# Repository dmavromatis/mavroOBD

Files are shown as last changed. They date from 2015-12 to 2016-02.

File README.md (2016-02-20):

# mavroOBD
Arduino (328P) based OBD port module

The goal of this project it to create an Arduino based OBD port module that can be used to enhance a vehicles capabilites.  For example, if you want door locks to close when moving faster than 5mph or to invoke/emulate certain CANbus buttons automatically at start up.

I have uploaded board designs for an OBD module I puchased from China.  It's a two board design.  Lower board solders to the pins of the OBD module and provides a 12V > 5V power supply.  Headers connect to the top board where the Atmel 328P and Microchip MCP2515 CAN Bus controller with SPI interface and MCP2551 CAN transceiver.

This project is based on an Arduino Uno and SeedStudio CAN shield just miniturized to fit in a OBD module.

The module enclousure was purchased from a company in China called AOTAI Industry Co.<br>
Part #: AOT-130N - ODB Connector with housing<br/>
Website: www.aotsisz.com

--------
License
--------

If you are distributing a modified version of the project, please describe the dates and details of your modifications (as described in section 3.3b of the CERN open hardware license).  If you are using a publicly available repository to track changes (which we encourage), you may simply list the URL of the repository here.

https://github.com/dmavromatis/mavroOBD

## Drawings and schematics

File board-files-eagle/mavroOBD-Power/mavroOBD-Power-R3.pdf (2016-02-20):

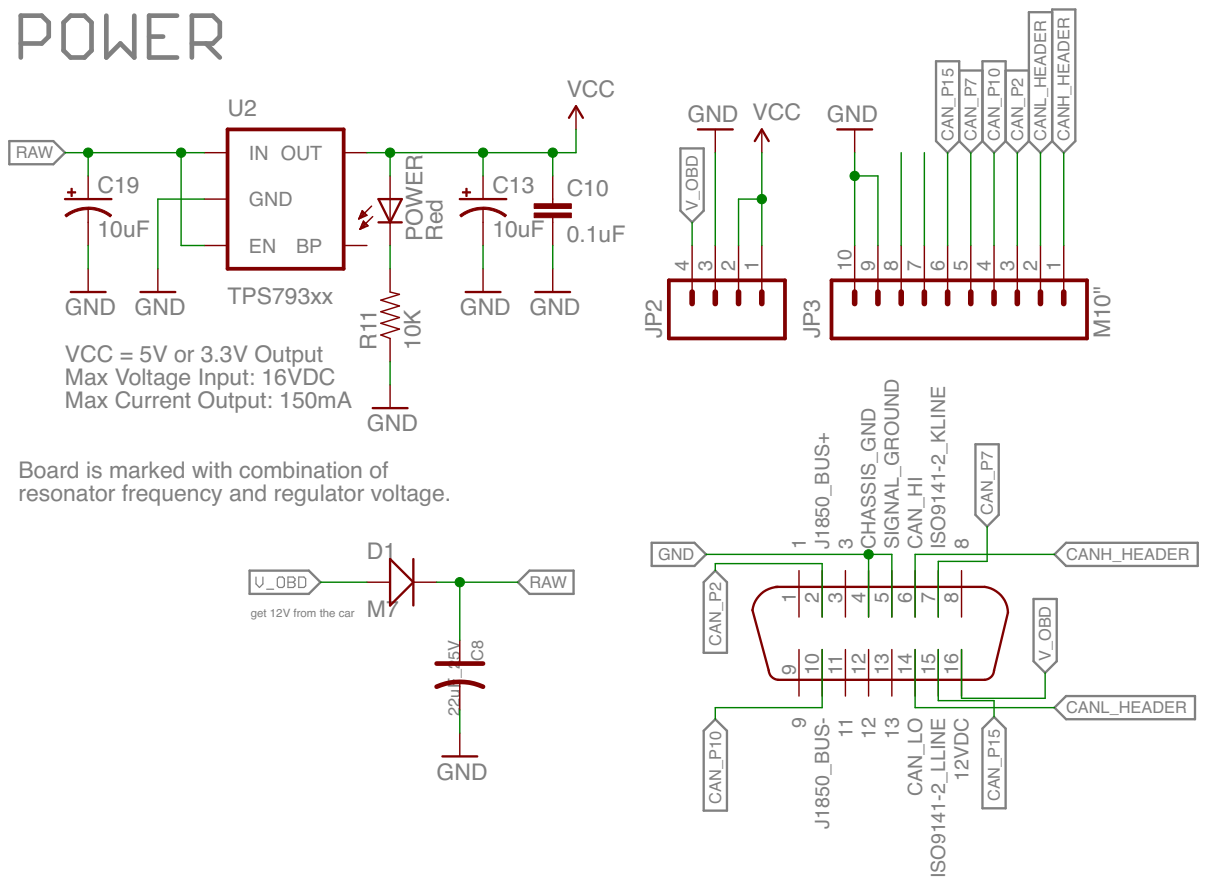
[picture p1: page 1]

Board is marked with combination of
resonator frequency and regulator voltage.

get 12V from the car

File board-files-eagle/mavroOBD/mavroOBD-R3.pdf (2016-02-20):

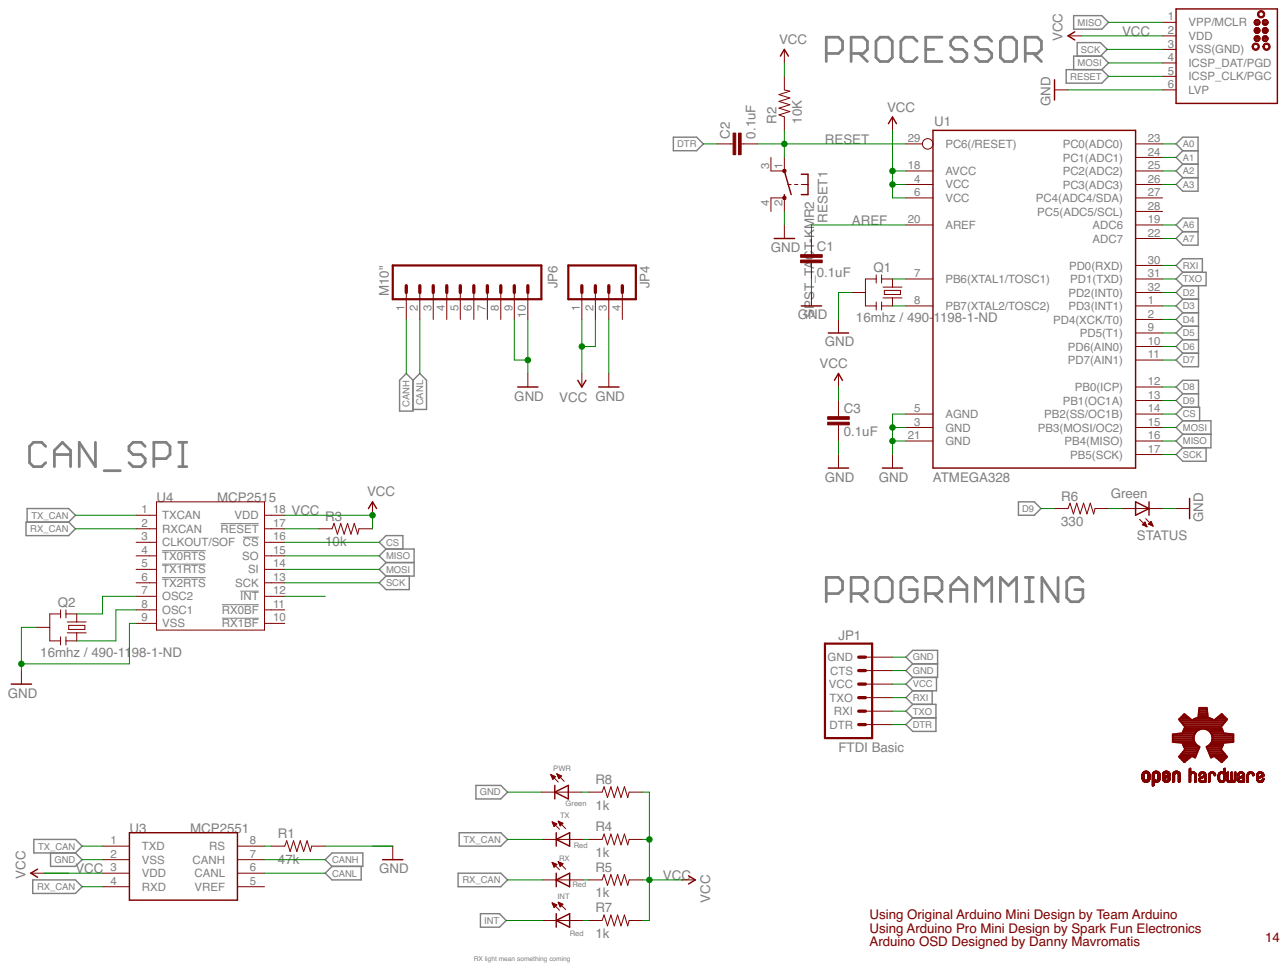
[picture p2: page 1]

PWR
Green Red Red Red
TXRX

RX light mean something coming

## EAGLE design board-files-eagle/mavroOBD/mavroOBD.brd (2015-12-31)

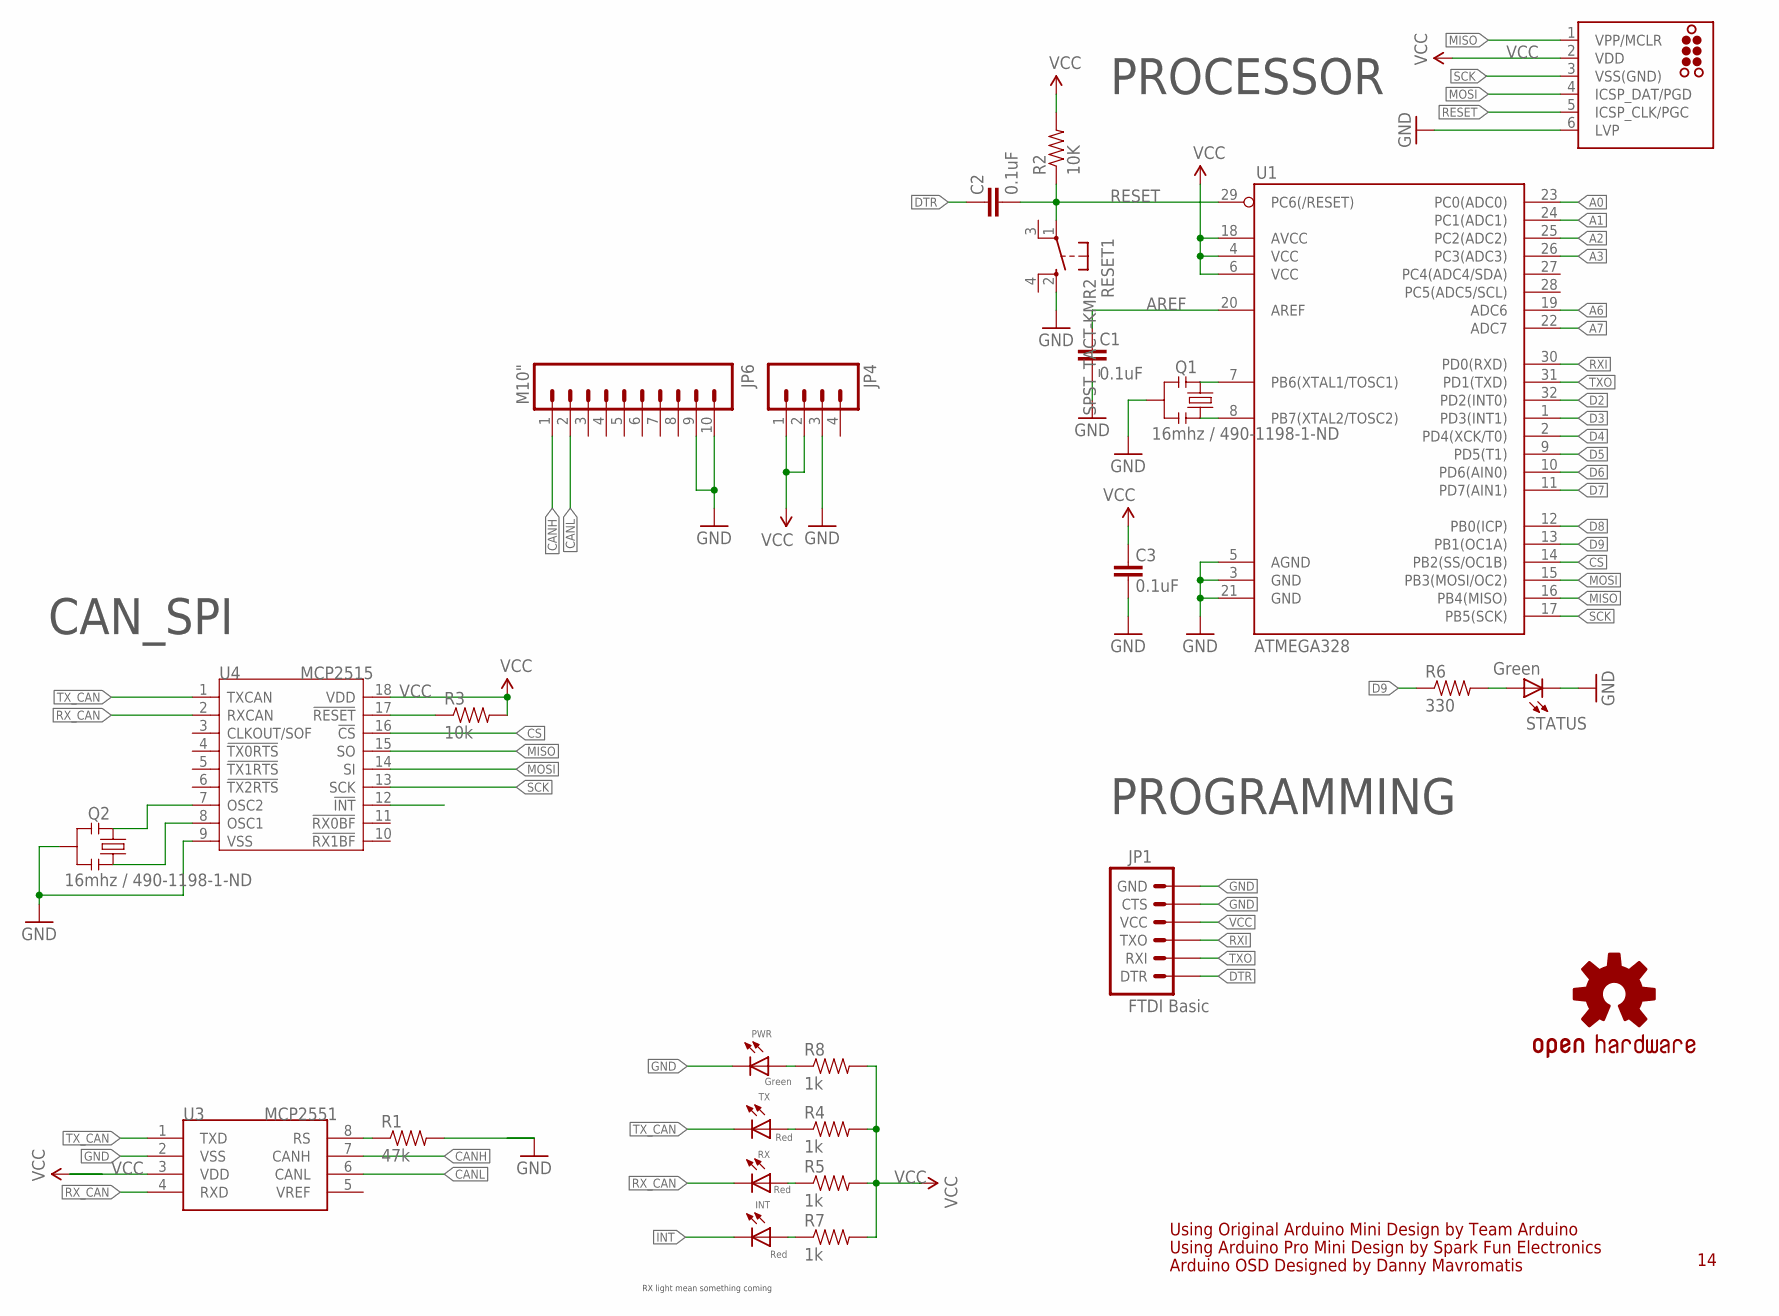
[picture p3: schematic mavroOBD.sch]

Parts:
C1, C2, C3: 0.1uF; 0603-CAP
INT: Red; 0603-LED-ALT1
J1: TC2030-MCP-NL
JP1: FTDI Basic; 1X06
JP4: M04PTH; 1X04
JP6: M10"; 1X10
PWR: Green; 0603-LED-ALT1
Q1, Q2: 16mhz / 490-1198-1-ND; RESONATOR-SMD-1:1
R1: 47k; 0603-RES
R2: 10K; 0603-RES
R3: 10k; 0603-RES
R4, R5, R7, R8: 1k; 0603-RES
R6: 330; 0603-RES
RESET1: SPST_TACT-KMR2; KMR2
RX: Red; 0603-LED-ALT1
STATUS: Green; 0603-LED-ALT1
TX: Red; 0603-LED-ALT1
U1: ATMEGA328; TQFP32-08
U3: MCP2551; SOIC8-6.0
U4: MCP2515; SOIC18
U$3: OSHW-LOGOS; OSHW-LOGO-S

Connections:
A0: U1.23 (PC0(ADC0))
A1: U1.24 (PC1(ADC1))
A2: U1.25 (PC2(ADC2))
A3: U1.26 (PC3(ADC3))
A6: U1.19 (ADC6)
A7: U1.22 (ADC7)
AREF: C1.2, U1.20 (AREF)
CANH: JP6.1, U3.7 (CANH)
CANL: JP6.2, U3.6 (CANL)
CS: U1.14 (PB2(SS/OC1B)), U4.16 (!CS)
D2: U1.32 (PD2(INT0))
D3: U1.1 (PD3(INT1))
D4: U1.2 (PD4(XCK/T0))
D5: U1.9 (PD5(T1))
D6: U1.10 (PD6(AIN0))
D7: U1.11 (PD7(AIN1))
D8: U1.12 (PB0(ICP))
D9: R6.1, U1.13 (PB1(OC1A))
DTR: C2.2, JP1.1 (DTR)
GND: C1.1, C3.1, J1.6 (LVP), JP1.5 (CTS), JP1.6 (GND), JP4.3, JP6.9, JP6.10, PWR.C, Q1.2, Q2.2, R1.2, RESET1.2 (S), STATUS.C, U1.3 (GND), U1.5 (AGND), U1.21 (GND), U3.2 (VSS), U4.9 (VSS)
INT: INT.C, U4.12 (!INT)
MISO: J1.1 (VPP/MCLR), U1.16 (PB4(MISO)), U4.15 (SO)
MOSI: J1.4 (ICSP_DAT/PGD), U1.15 (PB3(MOSI/OC2)), U4.14 (SI)
unnamed: Q1.3, U1.8 (PB7(XTAL2/TOSC2))
unnamed: Q1.1, U1.7 (PB6(XTAL1/TOSC1))
unnamed: R4.1, TX.A
unnamed: PWR.A, R8.1
unnamed: R6.2, STATUS.A
unnamed: R5.1, RX.A
unnamed: Q2.1, U4.7 (OSC2)
unnamed: Q2.3, U4.8 (OSC1)
unnamed: INT.A, R7.1
unnamed: R1.1, U3.8 (RS)
RESET: C2.1, J1.5 (ICSP_CLK/PGC), R2.1, RESET1.1, U1.29 (PC6(/RESET))
RST_N: R3.1, U4.17 (!RESET)
RXI: JP1.3 (TXO), U1.30 (PD0(RXD))
RX_CAN: RX.C, U3.4 (RXD), U4.2 (RXCAN)
SCK: J1.3 (VSS(GND)), U1.17 (PB5(SCK)), U4.13 (SCK)
TXO: JP1.2 (RXI), U1.31 (PD1(TXD))
TX_CAN: TX.C, U3.1 (TXD), U4.1 (TXCAN)
VCC: C3.2, J1.2 (VDD), JP1.4 (VCC), JP4.1, JP4.2, R2.2, R3.2, R4.2, R5.2, R7.2, R8.2, U1.4 (VCC), U1.6 (VCC), U1.18 (AVCC), U3.3 (VDD), U4.18 (VDD)

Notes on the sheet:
Using Original Arduino Mini Design by Team Arduino
Using Arduino Pro Mini Design by Spark Fun Electronics
CAN_SPI
RX light mean something coming
PROGRAMMING
PROCESSOR
Arduino OSD Designed by Danny Mavromatis

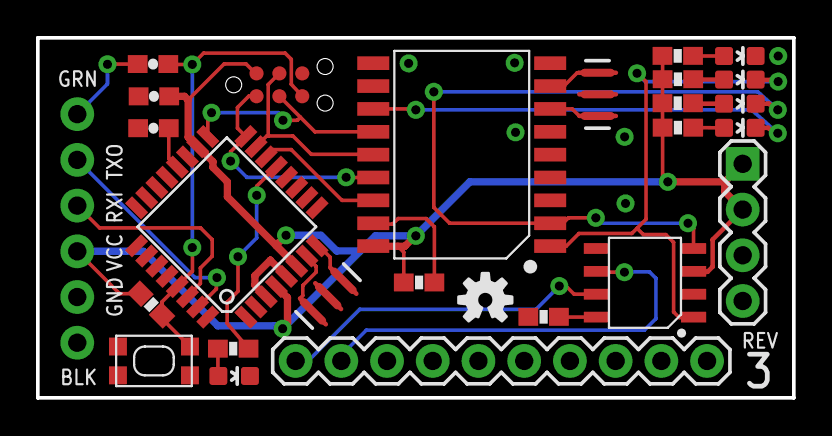
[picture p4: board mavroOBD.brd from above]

Board: 2 copper layers, 42.0 x 20.0 mm, 27 parts (1 on the bottom side), 28 nets.

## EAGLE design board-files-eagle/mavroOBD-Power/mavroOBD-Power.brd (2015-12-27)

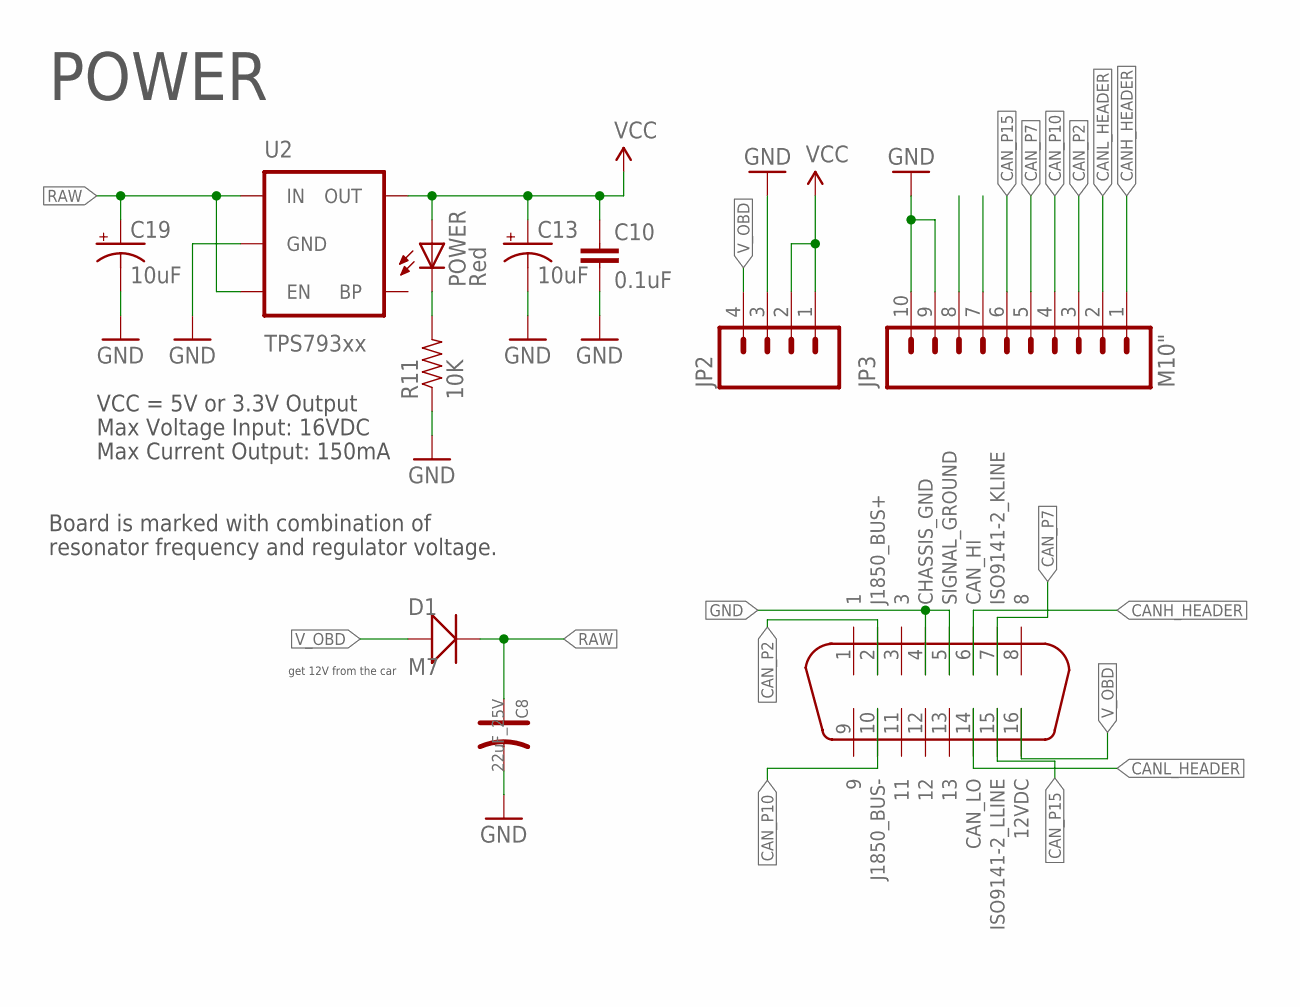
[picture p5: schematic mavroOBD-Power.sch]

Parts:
C8: 22uF_25V; ELECTRO-SMD-B-4.8MM
C10: 0.1uF; 0603-CAP
C13, C19: 10uF; EIA3216
D1: M7; D2010
JP2: M04PTH; 1X04
JP3: M10"; 1X10
POWER: Red; 0603-LED-ALT1
R11: 10K; 0603-RES
U2: TPS793xx; SOT23-5
U$1: ODBII-CON; OBDII-CON

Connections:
CANH_HEADER: JP3.1, U$1.6 (CAN_HI)
CANL_HEADER: JP3.2, U$1.14 (CAN_LO)
CAN_P2: JP3.3, U$1.2 (J1850_BUS+)
CAN_P7: JP3.5, U$1.7 (ISO9141-2_KLINE)
CAN_P10: JP3.4, U$1.10 (J1850_BUS-)
CAN_P15: JP3.6, U$1.15 (ISO9141-2_LLINE)
GND: C8.-, C10.2, C13.C (-), C19.C (-), JP2.3, JP3.9, JP3.10, R11.1, U2.2 (GND), U$1.4 (CHASSIS_GND), U$1.5 (SIGNAL_GROUND)
unnamed: POWER.C, R11.2
RAW: C8.+, C19.A (+), D1.-, U2.1 (IN), U2.3 (EN)
VCC_MAIN: C10.1, C13.A (+), JP2.1, JP2.2, POWER.A, U2.5 (OUT)
V_OBD: D1.+, JP2.4, U$1.16 (12VDC)

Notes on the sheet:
Max Voltage Input: 16VDC
Max Current Output: 150mA
Board is marked with combination of
resonator frequency and regulator voltage.
VCC = 5V or 3.3V Output
get 12V from the car
POWER

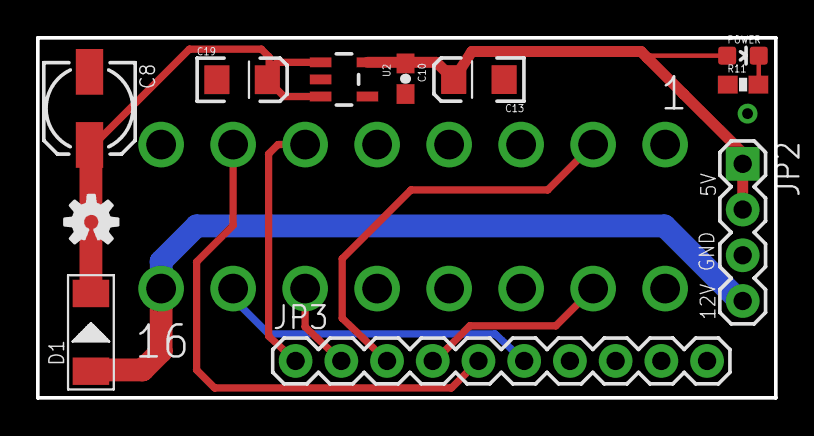
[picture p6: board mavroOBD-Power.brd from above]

Board: 2 copper layers, 41.0 x 20.0 mm, 12 parts (1 on the bottom side), 11 nets.

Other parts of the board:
U$2: OSHW-LOGOS; OSHW-LOGO-S

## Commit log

2015-12-24 mavroOSD
    Arduino (328P) based OBD port module
    [mavroOBD-Power.brd, mavroOBD-Power.sch, mavroOBD.brd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]
2015-12-24 Organizing Files
    [mavroOBD-Power.brd, mavroOBD-Power.sch, mavroOBD.brd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]
2015-12-27 Fixed incorrect pin assignment
    [mavroOBD-Power.brd, mavroOBD-Power.sch]
2015-12-31 Fixed Tag Connect ISP pin assignments
    [mavroOBD.brd, mavroOBD.sch]
2015-12-31 REV 3 Board - Sent to OSHPark
    Fixed a few via sizes, added VCC to ISP pin and REV 3 to silkscreen.
    [mavroOBD.brd, mavroOBD.sch]
2016-02-20 Added PDF versions of board schematic

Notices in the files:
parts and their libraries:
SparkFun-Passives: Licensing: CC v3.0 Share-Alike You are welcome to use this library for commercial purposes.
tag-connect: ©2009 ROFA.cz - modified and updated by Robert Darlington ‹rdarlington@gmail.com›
